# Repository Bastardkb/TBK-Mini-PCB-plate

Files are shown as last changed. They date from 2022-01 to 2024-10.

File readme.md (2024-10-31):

# TBK Mini PCB - plate

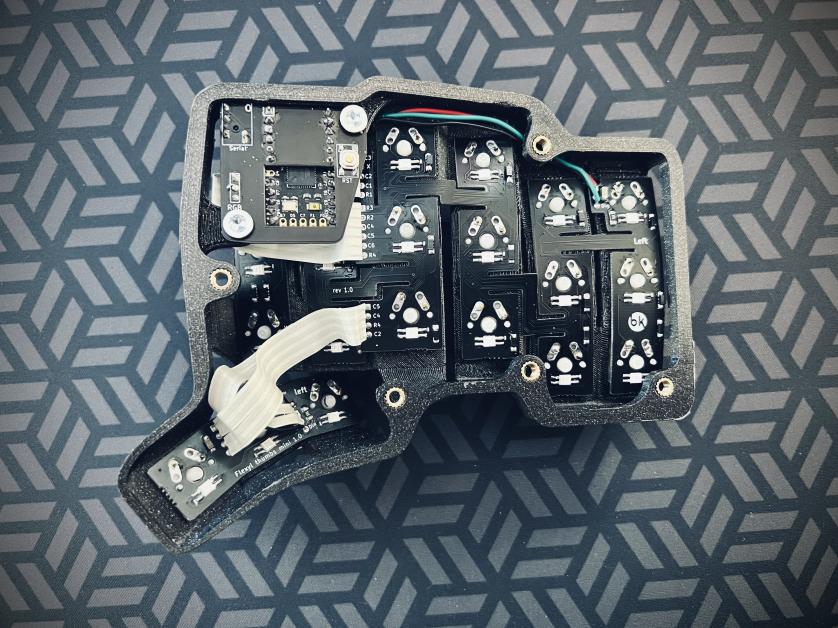
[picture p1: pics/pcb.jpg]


Flexible PCB made for the TBK Mini.

With per-key RGB.

This repository contains all files necessary to order a PCB.

If you want to modify the design files, the Kicad sources are included.
If you just want to order the PCBs, check out the Release section which contain the gerber files.

## How to order

Order with a 0.6mm or 0.8mm PCB thickness

## License

Licensed under CC BY-NC-SA 4.0
Copyright Quentin Lebastard 2021

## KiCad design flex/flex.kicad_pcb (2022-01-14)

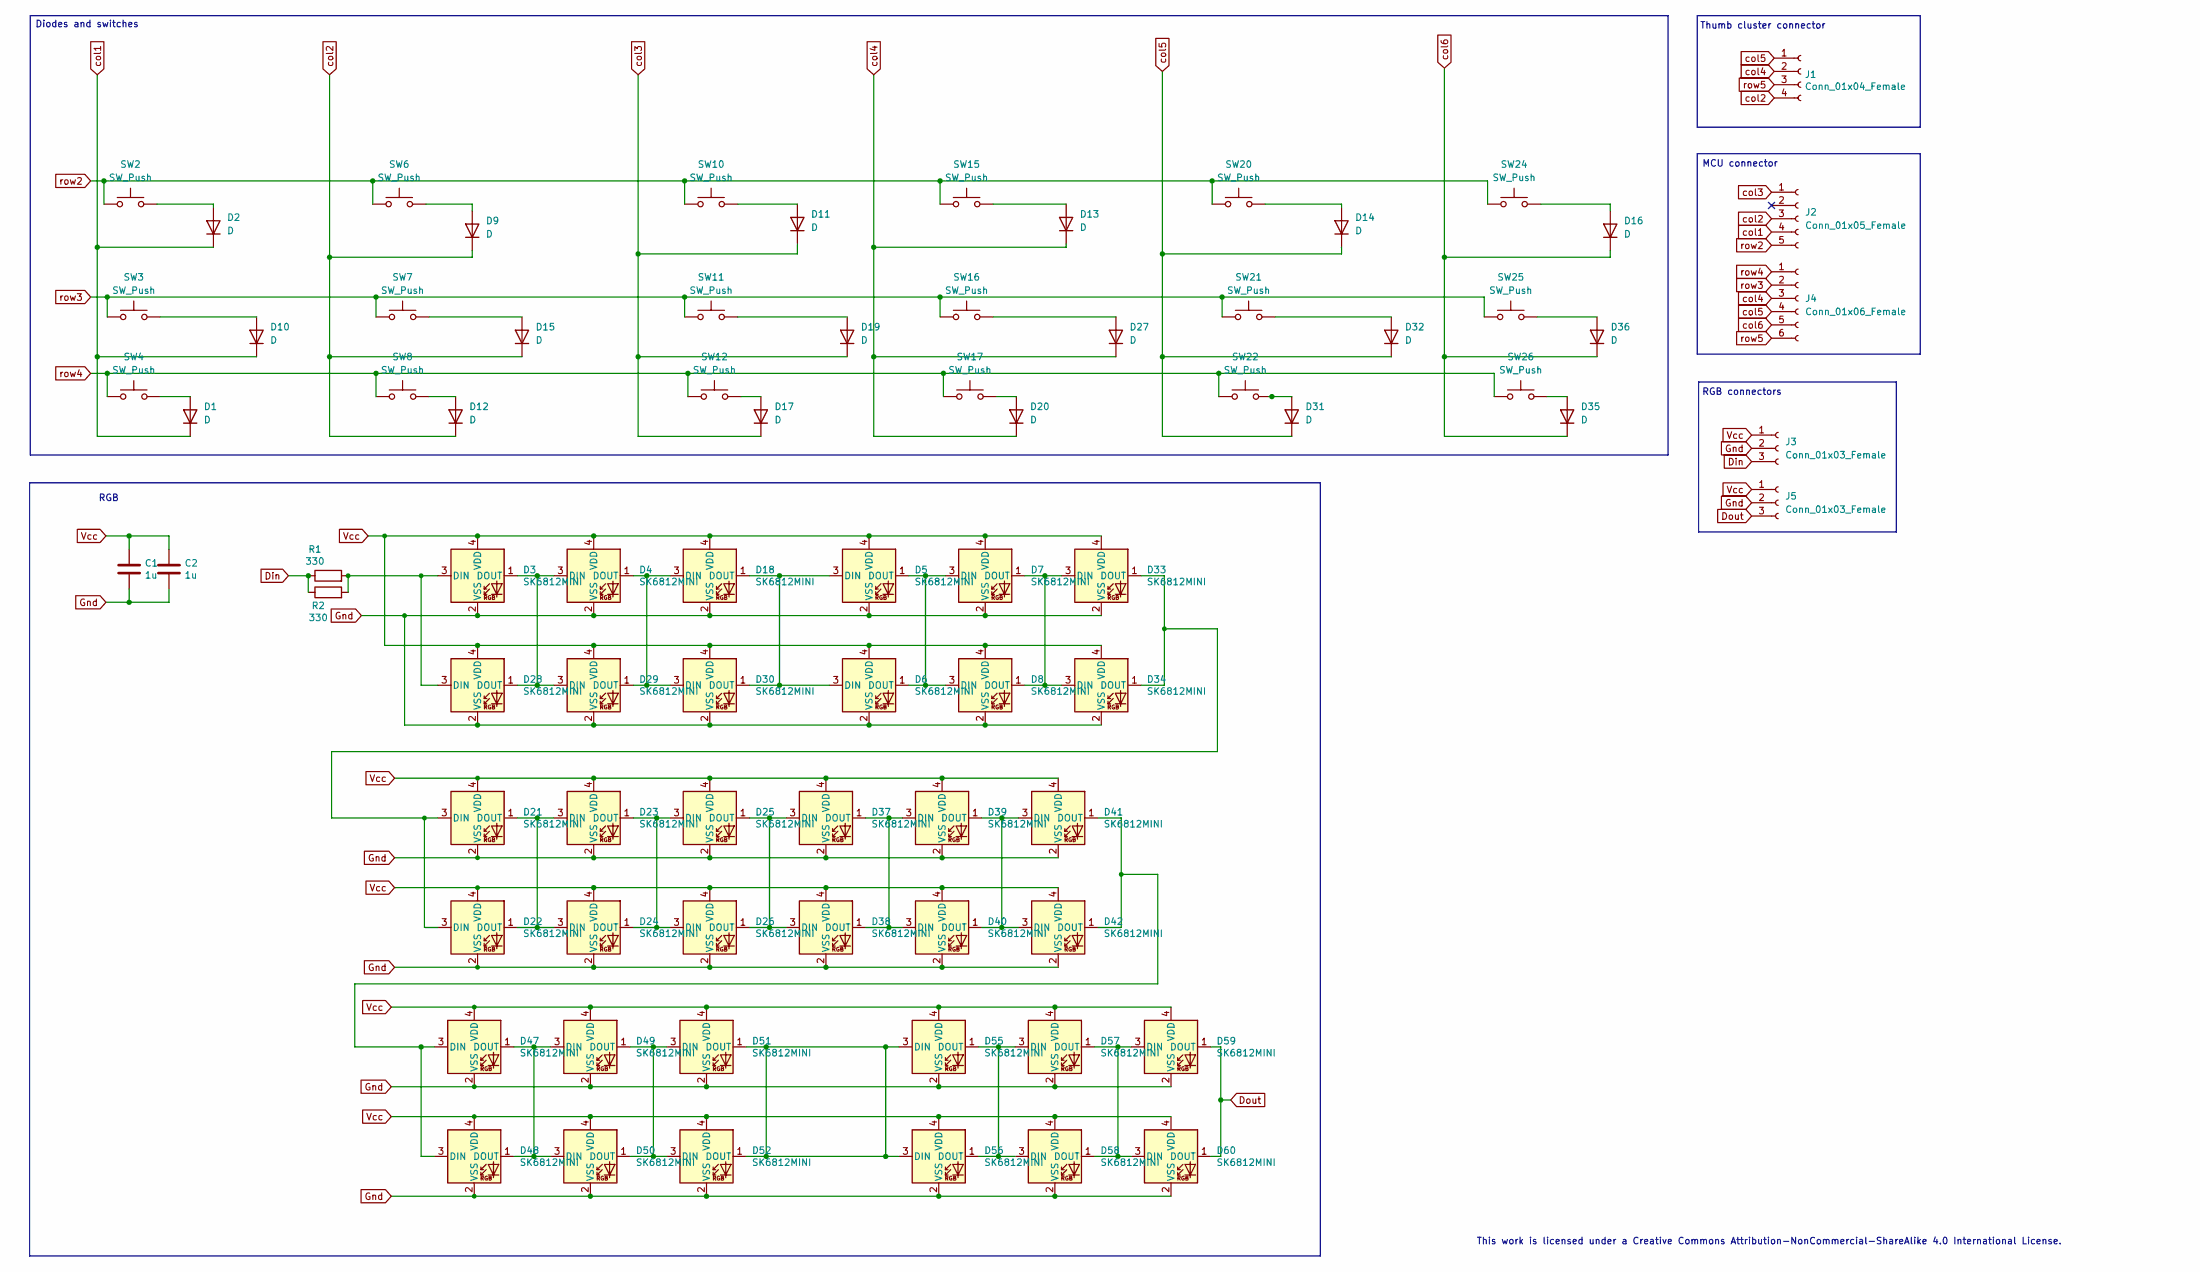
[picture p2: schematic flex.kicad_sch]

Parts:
C1, C2: 1u; C_1206_3216Metric_Pad1.42x1.75mm_HandSolder
D1, D2, D9, D10, D11, D12, D13, D14, D15, D16, D17, D19, D20, D27, D31, D32, D35, D36: D; Diode_TH_SOD123
D3, D4, D5, D7, D18, D21, D23, D25, D33, D37, D39, D41, D47, D49, D51, D55, D57, D59: SK6812MINI; YS-SK6812MINI-E_REVERSE
D6, D8, D22, D24, D26, D28, D29, D30, D34, D38, D40, D42, D48, D50, D52, D56, D58, D60: SK6812MINI; YS-SK6812MINI-E_REVERSE_NO_EDGECUT
J1: Conn_01x04_Female; PinHeader_1x04_P2.54mm_Vertical
J2: Conn_01x05_Female; PinHeader_1x05_P2.54mm_Vertical
J3, J5: Conn_01x03_Female; PinHeader_1x03_P2.54mm_Vertical
J4: Conn_01x06_Female; PinHeader_1x06_P2.54mm_Vertical
R1, R2: 330; R_1206_3216Metric_Pad1.42x1.75mm_HandSolder
SW2, SW3, SW4, SW6, SW7, SW8, SW10, SW11, SW12, SW15, SW16, SW17, SW20, SW21, SW22, SW24, SW25, SW26: SW_Push; SW_MX_reversible

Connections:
Din: J3.3, R1.1, R2.1
Dout: D59.1 (DOUT), D60.1 (DOUT), J5.3
Gnd: C1.2, C2.2, D3.2 (VSS), D4.2 (VSS), D5.2 (VSS), D6.2 (VSS), D7.2 (VSS), D8.2 (VSS), D18.2 (VSS), D21.2 (VSS), D22.2 (VSS), D23.2 (VSS), D24.2 (VSS), D25.2 (VSS), D26.2 (VSS), D28.2 (VSS), D29.2 (VSS), D30.2 (VSS), D33.2 (VSS), D34.2 (VSS), D37.2 (VSS), D38.2 (VSS), D39.2 (VSS), D40.2 (VSS), D41.2 (VSS), D42.2 (VSS), D47.2 (VSS), D48.2 (VSS), D49.2 (VSS), D50.2 (VSS), D51.2 (VSS), D52.2 (VSS), D55.2 (VSS), D56.2 (VSS), D57.2 (VSS), D58.2 (VSS), D59.2 (VSS), D60.2 (VSS), J3.2, J5.2
unnamed: D1.2 (A), SW4.2
unnamed: D2.2 (A), SW2.2
unnamed: D5.1 (DOUT), D6.1 (DOUT), D7.3 (DIN), D8.3 (DIN)
unnamed: D9.2 (A), SW6.2
unnamed: D10.2 (A), SW3.2
unnamed: D11.2 (A), SW10.2
unnamed: D12.2 (A), SW8.2
unnamed: D13.2 (A), SW15.2
unnamed: D14.2 (A), SW20.2
unnamed: D15.2 (A), SW7.2
unnamed: D16.2 (A), SW24.2
unnamed: D17.2 (A), SW12.2
unnamed: D5.3 (DIN), D6.3 (DIN), D18.1 (DOUT), D30.1 (DOUT)
unnamed: D4.1 (DOUT), D18.3 (DIN), D29.1 (DOUT), D30.3 (DIN)
unnamed: D19.2 (A), SW11.2
unnamed: D20.2 (A), SW17.2
unnamed: D21.1 (DOUT), D22.1 (DOUT), D23.3 (DIN), D24.3 (DIN)
unnamed: D21.3 (DIN), D22.3 (DIN), D33.1 (DOUT), D34.1 (DOUT)
unnamed: D23.1 (DOUT), D24.1 (DOUT), D25.3 (DIN), D26.3 (DIN)
unnamed: D25.1 (DOUT), D26.1 (DOUT), D37.3 (DIN), D38.3 (DIN)
unnamed: D27.2 (A), SW16.2
unnamed: D3.1 (DOUT), D4.3 (DIN), D28.1 (DOUT), D29.3 (DIN)
unnamed: D3.3 (DIN), D28.3 (DIN), R1.2, R2.2
unnamed: D31.2 (A), SW22.2
unnamed: D32.2 (A), SW21.2
unnamed: D7.1 (DOUT), D8.1 (DOUT), D33.3 (DIN), D34.3 (DIN)
unnamed: D35.2 (A), SW26.2
unnamed: D36.2 (A), SW25.2
unnamed: D37.1 (DOUT), D38.1 (DOUT), D39.3 (DIN), D40.3 (DIN)
unnamed: D39.1 (DOUT), D40.1 (DOUT), D41.3 (DIN), D42.3 (DIN)
unnamed: D41.1 (DOUT), D42.1 (DOUT), D47.3 (DIN), D48.3 (DIN)
unnamed: D47.1 (DOUT), D48.1 (DOUT), D49.3 (DIN), D50.3 (DIN)
unnamed: D49.1 (DOUT), D50.1 (DOUT), D51.3 (DIN), D52.3 (DIN)
unnamed: D51.1 (DOUT), D52.1 (DOUT), D55.3 (DIN), D56.3 (DIN)
unnamed: D55.1 (DOUT), D56.1 (DOUT), D57.3 (DIN), D58.3 (DIN)
unnamed: D57.1 (DOUT), D58.1 (DOUT), D59.3 (DIN), D60.3 (DIN)
Vcc: C1.1, C2.1, D3.4 (VDD), D4.4 (VDD), D5.4 (VDD), D6.4 (VDD), D7.4 (VDD), D8.4 (VDD), D18.4 (VDD), D21.4 (VDD), D22.4 (VDD), D23.4 (VDD), D24.4 (VDD), D25.4 (VDD), D26.4 (VDD), D28.4 (VDD), D29.4 (VDD), D30.4 (VDD), D33.4 (VDD), D34.4 (VDD), D37.4 (VDD), D38.4 (VDD), D39.4 (VDD), D40.4 (VDD), D41.4 (VDD), D42.4 (VDD), D47.4 (VDD), D48.4 (VDD), D49.4 (VDD), D50.4 (VDD), D51.4 (VDD), D52.4 (VDD), D55.4 (VDD), D56.4 (VDD), D57.4 (VDD), D58.4 (VDD), D59.4 (VDD), D60.4 (VDD), J3.1, J5.1
col1: D1.1 (K), D2.1 (K), D10.1 (K), J2.4
col2: D9.1 (K), D12.1 (K), D15.1 (K), J1.4, J2.3
col3: D11.1 (K), D17.1 (K), D19.1 (K), J2.1
col4: D13.1 (K), D20.1 (K), D27.1 (K), J1.2, J4.3
col5: D14.1 (K), D31.1 (K), D32.1 (K), J1.1, J4.4
col6: D16.1 (K), D35.1 (K), D36.1 (K), J4.5
row2: J2.5, SW2.1, SW6.1, SW10.1, SW15.1, SW20.1, SW24.1
row3: J4.2, SW3.1, SW7.1, SW11.1, SW16.1, SW21.1, SW25.1
row4: J4.1, SW4.1, SW8.1, SW12.1, SW17.1, SW22.1, SW26.1
row5: J1.3, J4.6

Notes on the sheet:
RGB
Diodes and switches
Thumb cluster connector
RGB connectors
MCU connector
This work is licensed under a Creative Commons Attribution-NonCommercial-ShareAlike 4.0 International License.

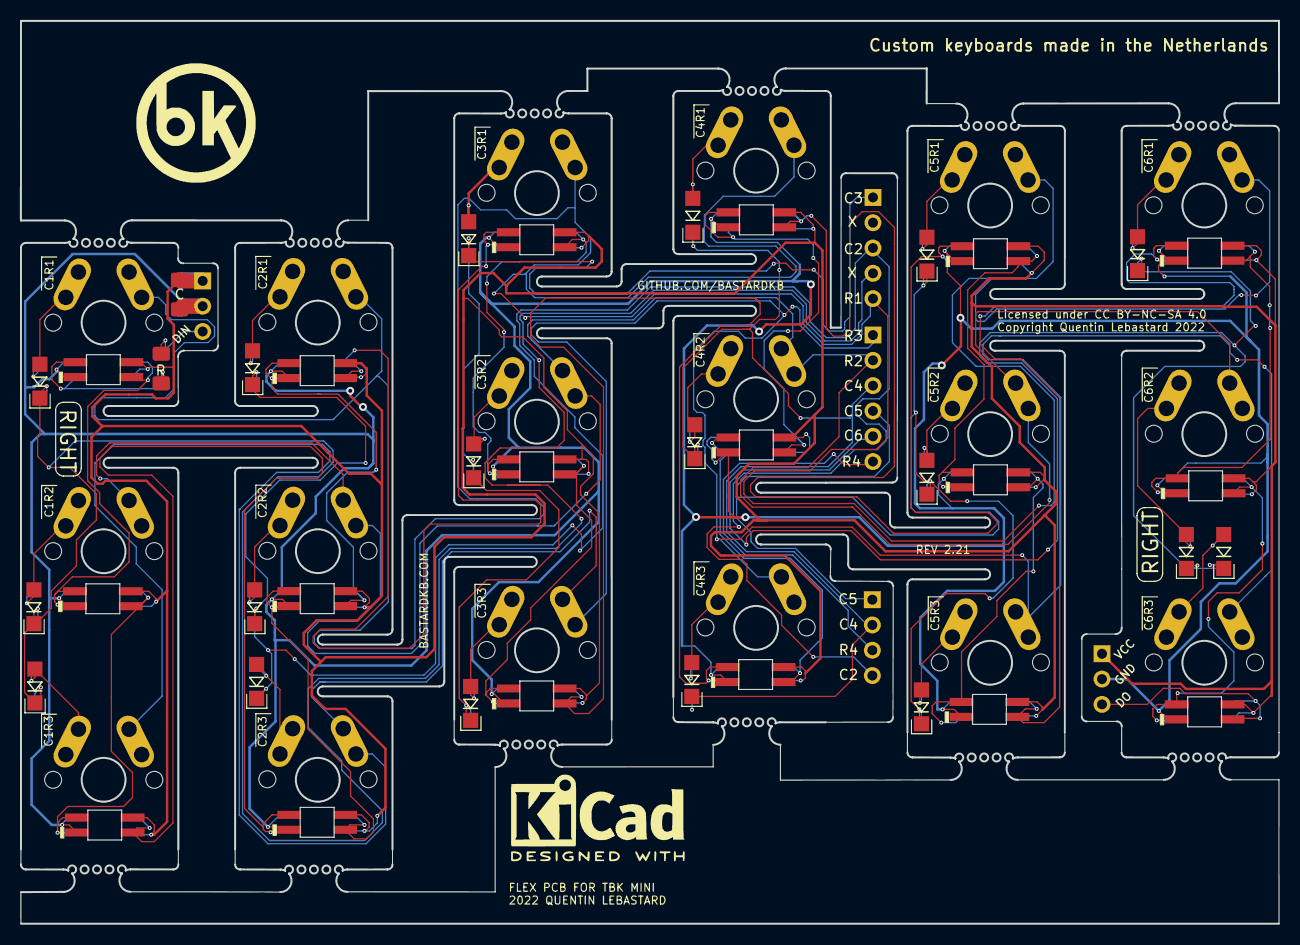
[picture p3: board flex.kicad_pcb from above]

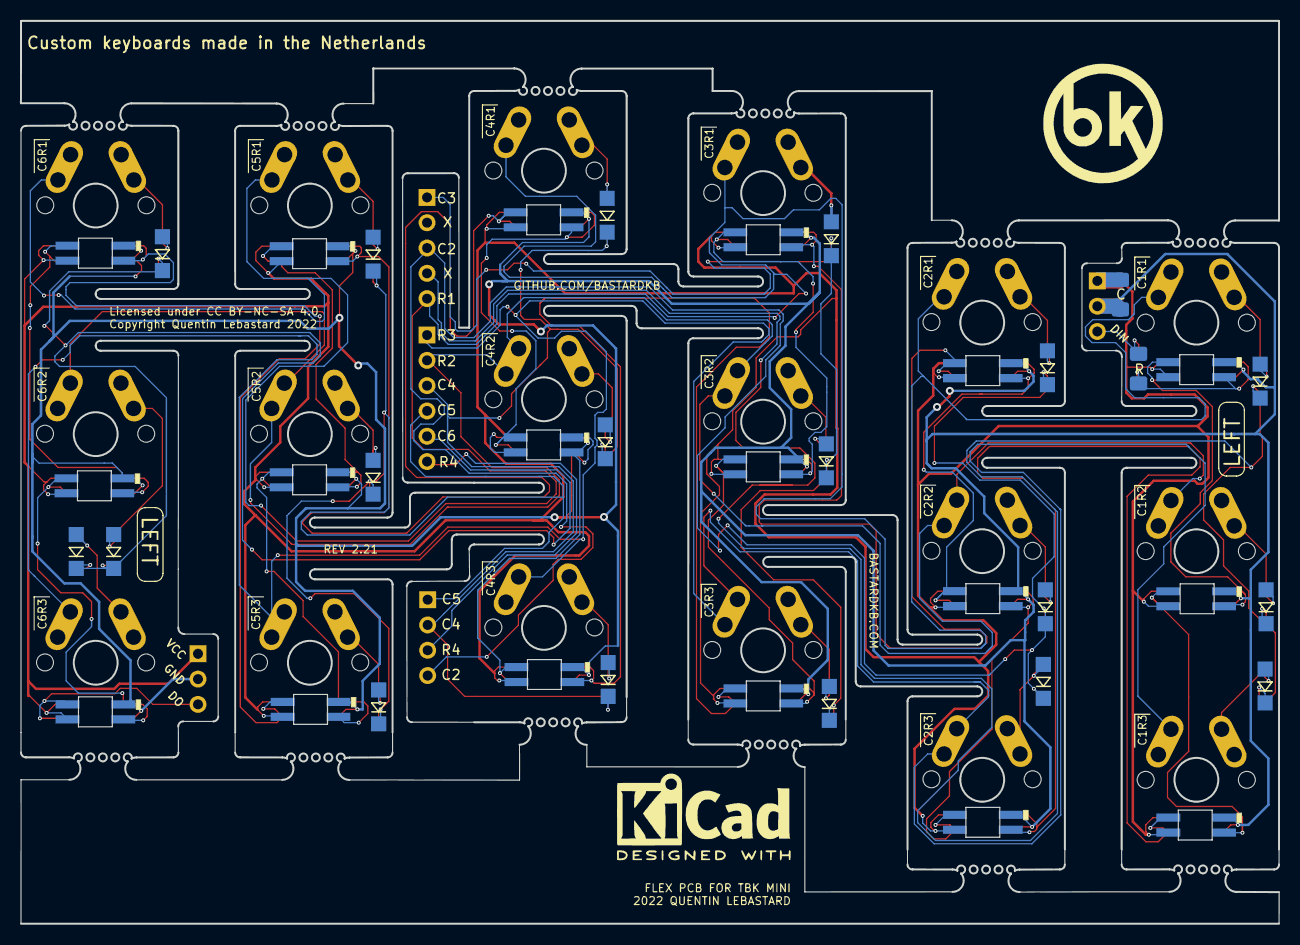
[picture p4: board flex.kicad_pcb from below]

Board: 2 copper layers, 126.3 x 90.6 mm, 81 parts (38 on the bottom side), 50 nets.

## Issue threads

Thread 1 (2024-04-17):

V3 notes

bstiq, 2024-04-17:
- [ ] assembled diodes on same spots as manual diodes (dual footprint)
- [ ] update edge cuts like on the 3x5
- [ ] 0.6mm thickness
- [ ] move all diodes to be oriented the same
- [ ] LEDs: mark pin 1 AND gnd pin
- [ ] separate ribbon cable connector in 2 parts, merge top part as well

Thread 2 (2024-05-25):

BOM and POS files

dudicoco, 2024-05-25:
Hi,

First of all, thanks for open sourcing the PCBs!

Is it possible to release BOM and POS files for the diodes so we can use PCB assembly instead of hand soldering them?

bstiq, 2024-05-25:
Hey,

Thank you for the kind words.
At the moment we don't have BOM and POS files for the PCB.
You should be able to generate them yourself from the Kicad project files.

For the 4x6 and 3x5 PCB I added 0603 footprints instead, as I was afraid the 1206 would be too large to accomodate the curvature when SMT assembled. You might want to modify the project file as well.

It's on my todo list to create an assembly-ready project, but the argos mouse is taking priority right now.

- Q.

dudicoco, 2024-05-25:
Thanks for the info.
I wonder, why didn't you go the pcb assembly route from the beginning considering that you are using these for production?

bstiq, 2024-05-27:
At the beginning we were populating all flex PCBs by hand. This was mostly due to time (routing everything and prototyping rounds) and financial constraints (SMD assembly on 0.6mm PCBs is expensive).
We are still doing so for the 3x6 ones, mostly because we haven't had time to modify them.

bstiq, 2024-05-28:
Yes, see the release section of both of those repositories.

They are marked as pre-release, but we have been using them with relative success.
The diodes are very small and tend to sometimes detach depending on your manufacturer.
The LEDs work well, just make sure with your manufacturer they're positioning them correctly (facing up/down, GND pin alignment)

dudicoco, 2024-05-29:
How's the diodes stability when assembled by JLCPCB?
Are there no BOM and POS files for the thumb PCB?

bstiq, 2024-05-29:
The diodes are mostly fine, every now and then one detaches - either because it moved during reflow or a bump during installation.
This is why there are still 1206 footprints on the PCB, so that you can add one manually if needed.

I'm not sure ordering the PCBs assembled is worth it if you're just going to do a couple builds - PCB assembly on 0.6mm thick black PCBs is expensive, and soldering the diodes manually is a matter of a couple minutes.

At the moment there's no BOM and POS files for the thumb PCBs.

Closed 2024-05-25.

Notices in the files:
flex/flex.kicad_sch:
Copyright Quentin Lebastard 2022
